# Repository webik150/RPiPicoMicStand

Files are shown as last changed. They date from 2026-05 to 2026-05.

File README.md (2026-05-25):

# Rapic Micsta
-# Raspberry Pi Pico Microphone Stand

This project aims to create a motorized microphone stand using old NEMA-17 stepper motors from Prusa MK3, controllable through a LAN web server hosted on a RPi Pico W using MicroPython.

The software part operates in two modes:

- **Pairing Mode**: When no Wi-Fi credentials are available at startup, or wi-fi connection is unsuccessful, the device creates a Wi-Fi Access Point (AP) and serves as a captive portal to allow users to configure the Wi-Fi settings. It is also possible to control the stand in this way in case you need to record in the field without any wifi for whatever reason.
- **Work Mode**: Once Wi-Fi credentials are saved, the device connects to the saved network and serves a control website on the local network.

### Updates
- **2025-04-21**: Update PCB to V2.1. It uses a much simpler and cheaper design. It's now just 2 layers instead of 4 and should be compatible with more types of TMC2209.
- **2024-12-15**: Made a V2 of the PCB, it's much smaller, uses SMD components and TMC2209 instead of A4988. I also added a connector for an OLED display.
- **2024-11-02**: PCB was tested out to be working so I added files for it along with pics. Feel free to have it made, I usually use JLCPCB for that. I also added an 8SEG display to the thing last minute, which means there's no connector for it on the PCB, however you can just solder 4 pins to the top of the Pico like in the pic below.

## Features
- Movement on X and Y axes (Forward/Back and Left/Right)
- Mic rotation on one axis
- Optional 8SEG display for debugging, info, stuff.
- Powered by 12V, idk how many A will be needed yet.
- I'll try to make as much of the actual structure 3D printable
- The software side is just a HTML page that sends commands through AJAX rn.

## Requirements

- **Hardware**:
  - PCB V2
    - 1x Raspberry Pi Pico W (Pico W 1 is recommended for now as Pico W 2 micropython is in pre-release)
    - 3x TMC2209. I'm using black+green V2, others *should* work, but sometimes the pin layout differs.
    - 1x 12V 3A power supply
    - 5V Buck converter (most I've seen support different input voltages 5-30V). Should support 3A.
    - (optionally) SSD1306 OLED display. 128x64 works out of the box, 128x32 needs additional tweaks.
  - Stand itself
    - No idea yet.

- **Software**:
  - MicroPython installed on the Pico W
  - MicroPython modules:
    - `network` for Wi-Fi functionality
    - `socket` for HTTP server implementation
    - `ujson` for saving/loading Wi-Fi credentials

## Installation & Setup
idk if this is correct, ChatGPT came up with these instructions and I haven't had time to check them yet lol.

1. **Flash MicroPython on Raspberry Pi Pico W**:
    - Download the MicroPython firmware for Pico W from [here](https://micropython.org/download/rp2-pico-w/).
    - Flash the firmware to your Pico W using the Thonny IDE or another method.

2. **Clone the Repository**

3. **Upload Files to Pico W**:
    - Use Thonny or another IDE to upload the required Python files to your Pico W. The key files include:
        - `main.py`: The main logic for the pairing mode, Wi-Fi connection, and work mode.
        - `img/`: Folder containing images for the UI.
        - `index.html`: The control webpage.
        - `modules/`: Folder containing Python modules for the HTTP server and Wi-Fi configuration.

4. **Modify the Configuration**:
    - If you want to set a custom SSID and password for the access point, edit the following lines in `main.py`:

5. **Running the Project**:
    - Plug in the Raspberry Pi Pico W, and the script will automatically run.
    - If the device is unable to connect to a Wi-Fi network, it will enter **Pairing Mode**, where you can connect to the access point `RPi_Pico_Setup` and configure the network settings.
    - Once the Wi-Fi credentials are applied, the Pico W will switch to **Work Mode** and serve the control webpage on the local network.

## Usage

### Pairing

1. Connect to the Wi-Fi access point `RPiMicStand` with the password `12345678`.
2. Your device (phone or computer) should automatically open a captive portal page.
3. Select a network from the dropdown and enter the Wi-Fi password.
4. Press "Apply" to save the credentials and switch to work mode.

### Work Mode

1. The Pico W connects to the saved Wi-Fi network and launches a web server on port `80`.
2. Access the control page by navigating to the Pico's IP address in a web browser (use `wlan.ifconfig()` to find the IP).
3. Use the sliders, buttons, and other controls on the page to interact with the Pico's GPIO pins or perform other tasks.

## PCB
KiCAD files are in the `PCB` folder. It could definitely be made much smaller, I might make a v2 sometime just for the fuck of it, or if necessary. 

Right now RaPiPiMiSt uses 14 GPIO pins (3 for each motor, 5 for the display).

### Possible improvements (V2 Wishlist):
  * Use SMD components instead of THT. It's just resistors and capacitors so nothing fancy.
  * Get rid of the DIP switches and control the pins through Pico, there's enough PINS still.
    * Should this even be configurable? I could theoretically hardwire it so that X/Y motors use 1/2 step and Z motor uses 1/16 step.
    * If configurable, each motor would use 6 pins (23 total, which still fits). Alternatively only Z axis could be configurable.
  * Add a connector for the display directly on the board
  * Maybe switch over to an OLED display, which is cheaper, much more versatile and uses one less pin.
    * Downside is I have to learn to make an UI for that, but it sounds fun.
  * The power pin is made for a classic dupont pin rn, might be better to put it on the edge somewhere and make it use an actual on-board connector. Less wires.
  * I limited myself to 2 layer PCB, but 4 layer one isn't actually that much more expensive and could make stuff much smaller.
  * The A4988 is loud and has no stall detection. I could switch to a TMC2209 which is bit more expensive but would allow for automatic calibration and less pins used.
  * Idk what the fail rate of these drivers is but they could be soldered to the board instead of using a socket.
  * I could actually use vias instead of trying to go around everything lol.
  * The pico could be soldered directly to the board without any headers

RaPiPiMiSt PCB v01
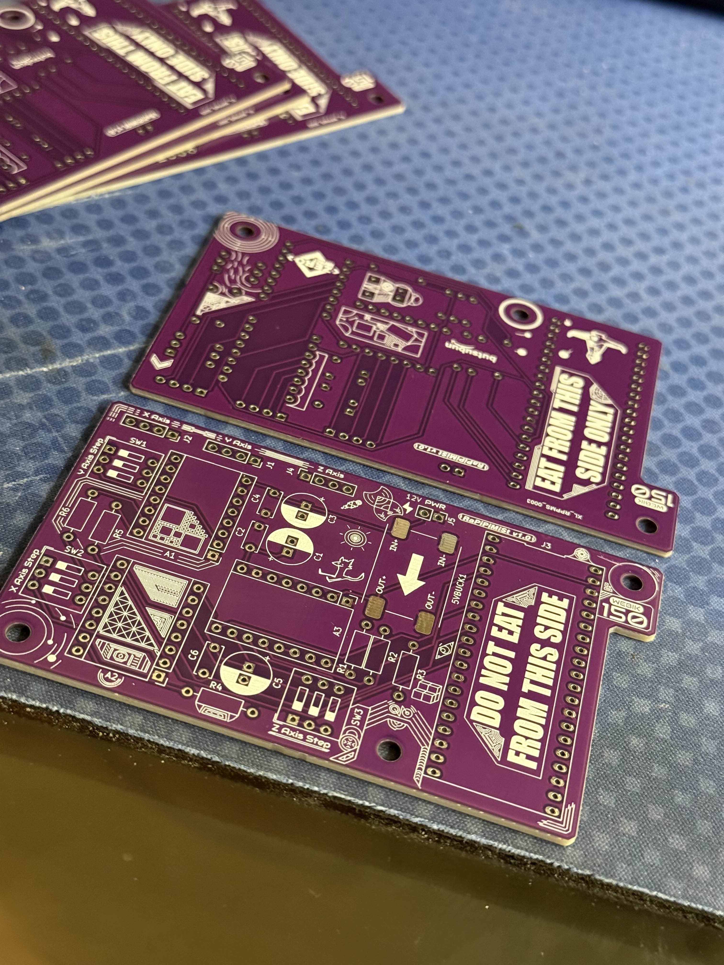
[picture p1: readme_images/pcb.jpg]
Plain PCB

Finished thing
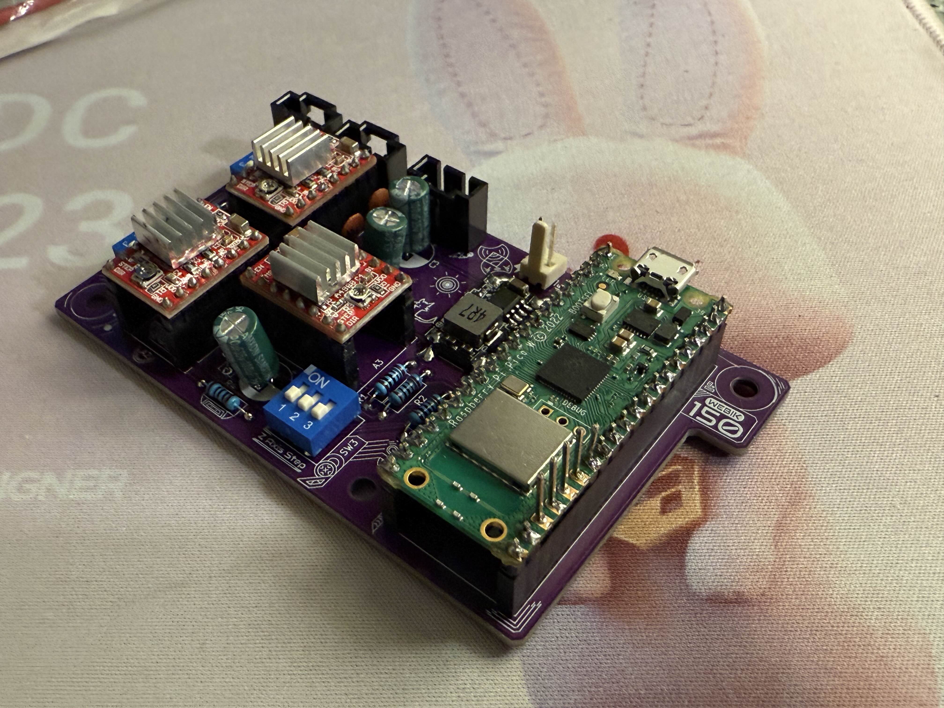
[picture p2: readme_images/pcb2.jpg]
Soldered PCB


## Pics

**Control website**:
TODO
Captive Portal

**Stand**:
TODO
Captive Portal

## License

This project is licensed under the MIT License. See the [LICENSE](LICENSE) file for details.

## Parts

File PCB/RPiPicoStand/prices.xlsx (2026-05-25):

Reference | Value | Datasheet | Footprint | Qty | DNP | Price per lot | Price Total | Price Total for single board
5VBUCK1 | ~ |  | Library:BUCK Converter 5-30V 5V 3A smd | 1 | 13.6 | 68 | 13.6 | 68
A1,A2,A3 | Pololu_Breakout_A4988 | https://www.pololu.com/product/2980/pictures | Module:Pololu_Breakout-16_15.2x20.3mm | 3 | 26.6 | 133 | 79.8 | 133
C1,C3,C5 | C_Polarized_Small | ~ | Capacitor_THT:CP_Radial_D7.5mm_P2.50mm | 3 | 1 | 130 | 3 | 130
C2,C4,C6 | C_Small | ~ | Capacitor_THT:C_Disc_D6.0mm_W2.5mm_P5.00mm | 3 | 1 | 140 | 3 | 140
J1,J2,J4 | Conn_01x04_Pin | ~ | Connector_PinSocket_2.54mm:PinSocket_1x04_P2.54mm_Vertical | 3 | 10 | 100 | 30 | 100
J3 | Conn_02x20_Counter_Clockwise | ~ | Connector:DIP-40_709_ELL socket W18Pins W21 | 1 | 5 | 25 | 5 | 25
J5 | Conn_01x02_Pin | ~ | Connector_PinHeader_2.54mm:PinHeader_1x02_P2.54mm_Vertical | 1 | 1 | 10 | 1 | 10
R1,R2,R3,R4,R5,R6 | R_Small | ~ | Resistor_THT:R_Axial_DIN0207_L6.3mm_D2.5mm_P10.16mm_Horizontal | 6 | 1 | 100 | 6 | 100
SW1,SW2,SW3 | SW_DIP_x03 | ~ | Button_Switch_THT:SW_DIP_SPSTx03_Slide_9.78x9.8mm_W7.62mm_P2.54mm | 3 | 32 | 32 | 96 | 32
Rpi Pico W |  |  |  | 1 | 150 | 150 | 150 | 150
PCB |  |  |  | 1 | 50 | 250 | 50 | 250
 |  |  |  |  |  |  | 437.4 | 1138

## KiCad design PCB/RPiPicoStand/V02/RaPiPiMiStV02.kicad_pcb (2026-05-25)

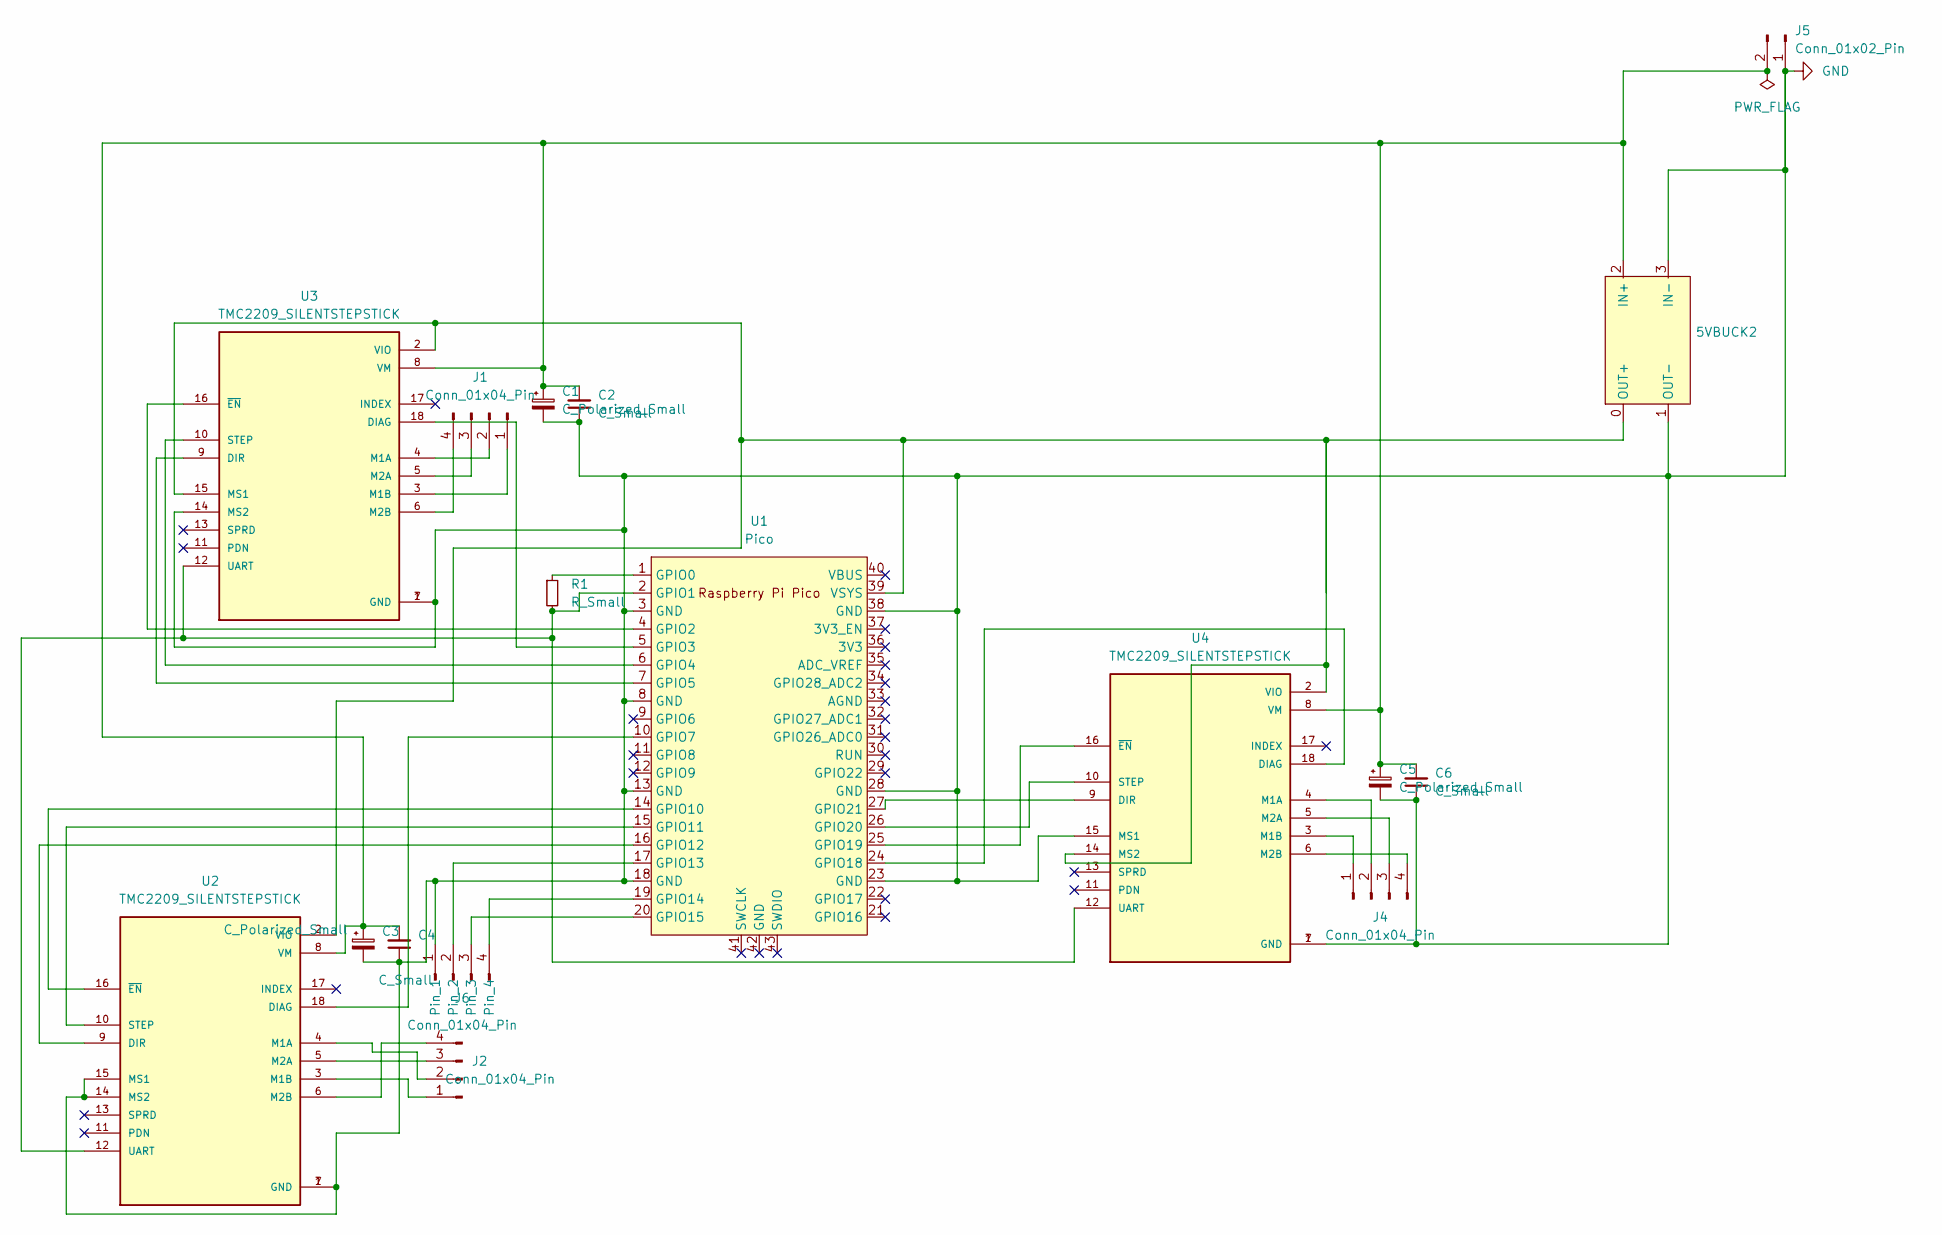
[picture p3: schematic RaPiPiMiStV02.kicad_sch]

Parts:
5VBUCK2: BUCK Converter 5-30V 5V 3A smd
C1, C3, C5: C_Polarized_Small; CP_Elec_6.3x7.7
C2, C4, C6: C_Small; C_0603_1608Metric
J1, J2, J4, J6: Conn_01x04_Pin; PinSocket_1x04_P2.54mm_Vertical
J5: Conn_01x02_Pin; PinHeader_1x02_P2.54mm_Vertical
R1: R_Small; R_0603_1608Metric_Pad0.98x0.95mm_HandSolder
U1: Pico; RPi_Pico_SMD_TH
U2, U3, U4: TMC2209_SILENTSTEPSTICK; MODULE_TMC2209_SILENTSTEPSTICK; PARTREV 1.20

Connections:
GND: 5VBUCK2.1 (OUT-), 5VBUCK2.3 (IN-), C1.2, C2.1, C3.2, C4.1, C5.2, C6.1, J5.1, J6.1, U1.3 (GND), U1.8 (GND), U1.13 (GND), U1.18 (GND), U1.23 (GND), U1.28 (GND), U1.38 (GND), U2.1 (GND), U2.7 (GND), U2.14 (MS2), U2.15 (MS1), U3.1 (GND), U3.7 (GND), U3.14 (MS2), U4.1 (GND), U4.7 (GND), U4.15 (MS1)
unnamed: 5VBUCK2.2 (IN+), C1.1, C2.2, C3.1, C4.2, C5.1, C6.2, J5.2, U2.8 (VM), U3.8 (VM), U4.8 (VM)
unnamed: 5VBUCK2.0 (OUT+), U1.39 (VSYS), U2.2 (VIO), U3.2 (VIO), U3.15 (MS1), U4.2 (VIO), U4.14 (MS2)
unnamed: J1.1, U3.3 (M1B)
unnamed: J1.2, U3.4 (M1A)
unnamed: J1.3, U3.5 (M2A)
unnamed: J1.4, U3.6 (M2B)
unnamed: J2.1, U2.3 (M1B)
unnamed: J2.2, U2.4 (M1A)
unnamed: J2.3, U2.5 (M2A)
unnamed: J2.4, U2.6 (M2B)
unnamed: J4.1, U4.3 (M1B)
unnamed: J4.2, U4.4 (M1A)
unnamed: J4.3, U4.5 (M2A)
unnamed: J4.4, U4.6 (M2B)
unnamed: J6.2, U1.17 (GPIO13)
unnamed: J6.3, U1.20 (GPIO15)
unnamed: J6.4, U1.19 (GPIO14)
unnamed: R1.1, U1.1 (GPIO0)
unnamed: R1.2, U1.2 (GPIO1), U2.12 (UART), U3.12 (UART), U4.12 (UART)
unnamed: U1.4 (GPIO2), U3.16 (~EN)
unnamed: U1.5 (GPIO3), U3.18 (DIAG)
unnamed: U1.6 (GPIO4), U3.10 (STEP)
unnamed: U1.7 (GPIO5), U3.9 (DIR)
unnamed: U1.10 (GPIO7), U2.18 (DIAG)
unnamed: U1.14 (GPIO10), U2.16 (~EN)
unnamed: U1.15 (GPIO11), U2.10 (STEP)
unnamed: U1.16 (GPIO12), U2.9 (DIR)
unnamed: U1.24 (GPIO18), U4.18 (DIAG)
unnamed: U1.25 (GPIO19), U4.16 (~EN)
unnamed: U1.26 (GPIO20), U4.10 (STEP)
unnamed: U1.27 (GPIO21), U4.9 (DIR)

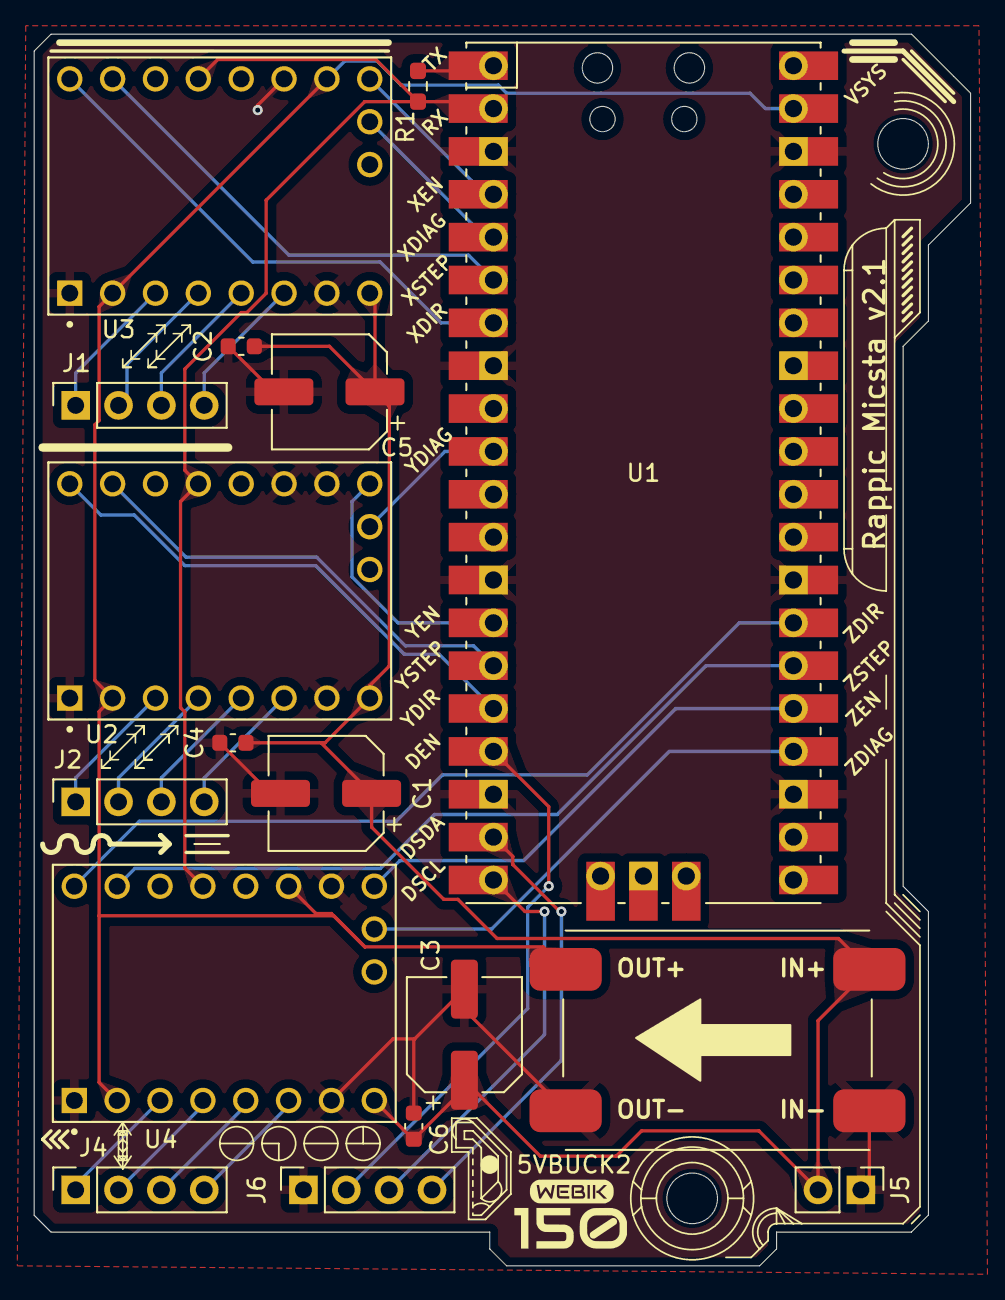
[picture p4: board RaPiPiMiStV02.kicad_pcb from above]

Board: 2 copper layers, 55.5 x 73.0 mm, 17 parts (0 on the bottom side), 32 nets.

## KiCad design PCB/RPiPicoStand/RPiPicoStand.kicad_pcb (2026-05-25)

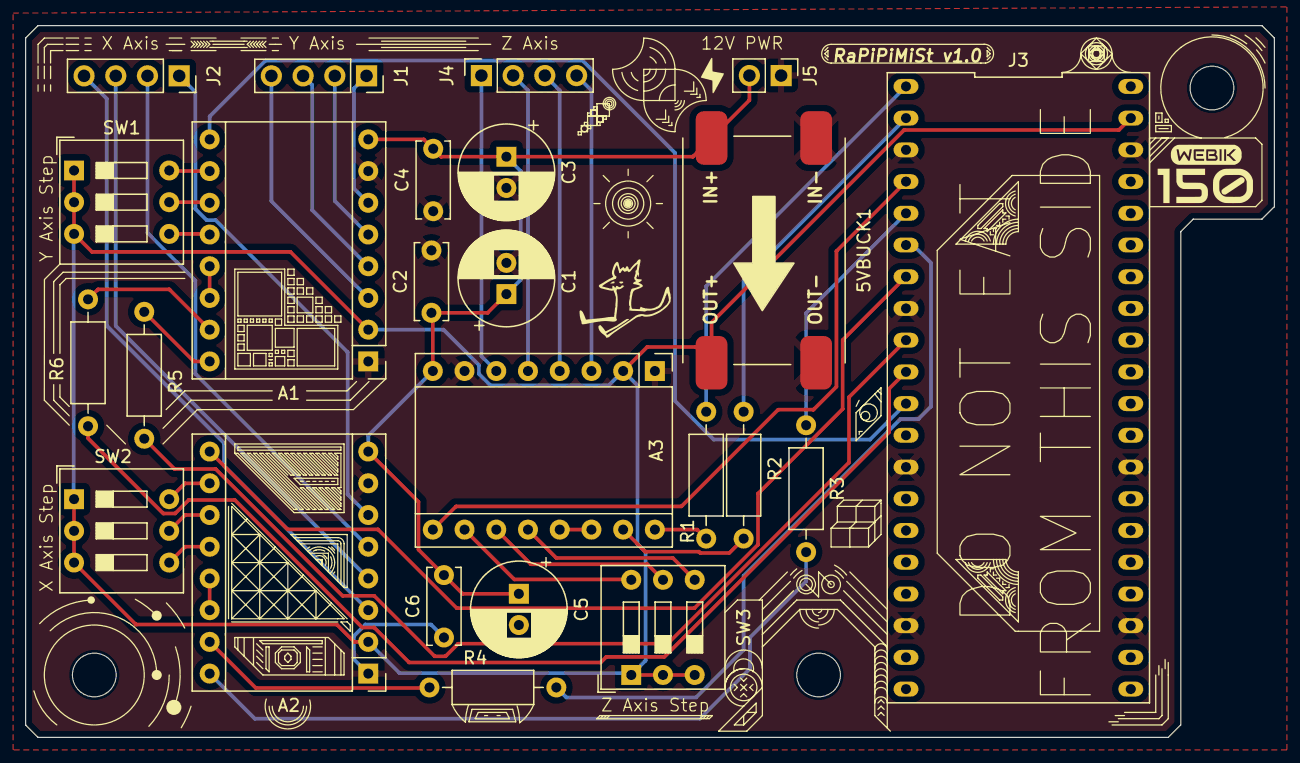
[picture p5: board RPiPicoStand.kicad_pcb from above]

Board: 2 copper layers, 100.0 x 57.0 mm, 25 parts (1 on the bottom side), 39 nets.

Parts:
5VBUCK1: BUCK Converter 5-30V 5V 3A smd
A1, A2, A3: Pololu_Breakout_A4988; Pololu_Breakout-16_15.2x20.3mm
C1, C3, C5: C_Polarized_Small; CP_Radial_D7.5mm_P2.50mm
C2, C4, C6: C_Small; C_Disc_D6.0mm_W2.5mm_P5.00mm
J1, J2, J4: Conn_01x04_Pin; PinSocket_1x04_P2.54mm_Vertical
J3: Conn_02x20_Counter_Clockwise; DIP-40_709_ELL socket W18Pins W21
J5: Conn_01x02_Pin; PinHeader_1x02_P2.54mm_Vertical
R1, R2, R3, R4, R5, R6: R_Small; R_Axial_DIN0207_L6.3mm_D2.5mm_P10.16mm_Horizontal
SW1, SW2, SW3: SW_DIP_x03; SW_DIP_SPSTx03_Slide_9.78x9.8mm_W7.62mm_P2.54mm
aa: LOGO

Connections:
GND: 5VBUCK1.1 (OUT-), 5VBUCK1.3 (IN-), A1.1 (GND), A1.7 (GND), A2.1 (GND), A2.7 (GND), A3.1 (GND), A3.7 (GND), C1.2, C2.1, C3.2, C4.1, C5.2, C6.1, J3.3, J3.8, J3.13, J3.18, J3.23, J3.28, J3.38, J5.1
unnamed: 5VBUCK1.2 (IN+), A1.8 (VMOT), A2.8 (VMOT), A3.8 (VMOT), C1.1, C2.2, C3.1, C4.2, C5.1, C6.2, J5.2
unnamed: 5VBUCK1.0 (OUT+), A1.2 (VDD), A2.2 (VDD), A3.2 (VDD), J3.39, SW1.1, SW1.2, SW1.3, SW2.1, SW2.2, SW2.3, SW3.1, SW3.2, SW3.3
unnamed: A1.4 (1A), J1.3
unnamed: A1.3 (1B), J1.4
unnamed: A1.5 (2A), J1.2
unnamed: A1.6 (2B), J1.1
unnamed: A1.16 (DIR), R5.2
unnamed: A1.10 (MS1), SW1.6
unnamed: A1.11 (MS2), SW1.5
unnamed: A1.12 (MS3), SW1.4
unnamed: A1.15 (STEP), R6.1
unnamed: A1.9 (~ENABLE), J3.11
unnamed: A2.4 (1A), J2.3
unnamed: A2.3 (1B), J2.4
unnamed: A2.5 (2A), J2.2
unnamed: A2.6 (2B), J2.1
unnamed: A2.16 (DIR), R3.1
unnamed: A2.10 (MS1), SW2.6
unnamed: A2.11 (MS2), SW2.5
unnamed: A2.12 (MS3), SW2.4
unnamed: A2.15 (STEP), R4.1
unnamed: A2.9 (~ENABLE), J3.7
unnamed: A3.4 (1A), J4.3
unnamed: A3.3 (1B), J4.4
unnamed: A3.5 (2A), J4.2
unnamed: A3.6 (2B), J4.1
unnamed: A3.16 (DIR), R1.1
unnamed: A3.10 (MS1), SW3.6
unnamed: A3.11 (MS2), SW3.5
unnamed: A3.12 (MS3), SW3.4
unnamed: A3.15 (STEP), R2.1
unnamed: A3.9 (~ENABLE), J3.4
unnamed: J3.1, R1.2
unnamed: J3.2, R2.2
unnamed: J3.5, R3.2
unnamed: J3.6, R4.2
unnamed: J3.9, R5.1
unnamed: J3.10, R6.2

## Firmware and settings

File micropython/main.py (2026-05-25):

import sys
import utime
import network
import uasyncio
from modules.log import Log
from modules.rpicostand import RPicoStand
# server
from phew import logging, server, access_point, dns, connect_to_wifi
from phew.template import render_template
from phew.server import redirect, Response
from machine import Pin

# while True:
#     sparkle_dissolve(rpicostand.display.oled, 1000, 50)
#     expanding_polygon(rpicostand.display.oled, center_x=64, center_y=16, duration_ms=500, sides=6, initial_rotation=30)
#     expanding_polygon(rpicostand.display.oled, center_x=64, center_y=16, duration_ms=500, sides=6, initial_rotation=0)
#     expanding_polygon(rpicostand.display.oled, center_x=64, center_y=16, duration_ms=500, sides=4, initial_rotation=0)
#     expanding_polygon(rpicostand.display.oled, center_x=64, center_y=16, duration_ms=500, sides=3, initial_rotation=0)
#     expanding_polygon(rpicostand.display.oled, center_x=64, center_y=16, duration_ms=500, sides=16, initial_rotation=0)
#     random_expanding_polygons(rpicostand.display.oled, duration_ms=100, num=5, state=1)
#     random_expanding_polygons(rpicostand.display.oled, duration_ms=100, num=5, state=0)
#     random_expanding_polygons(rpicostand.display.oled, duration_ms=100, num=5, state=-1)
from modules.displays import OLED_SSD1306

print("Starting up")
led = Pin("LED", Pin.OUT)
led(1)
Pin(21, Pin.OUT)(1)
utime.sleep_ms(500)
led(0)


@server.route("/", methods=['GET', 'POST'])
def index(request):
    """ Render the Index page and respond to form requests """
    if request.method == 'GET':
        # logging.debug("Get request")
        # give the webpage access to python variables
        return index_page()
    if request.method == 'POST':
        text = request.form.get("text", None)
        #logging.debug(f'posted message: {text}')
        return index_page()

@server.route("/restart", methods=['POST'])
def restart(request):
    #uasyncio.create_task(restart_after_while())
    rpicostand.display.oled.fill(0)
    rpicostand.display.display_centered_text("Restarting...", 8)
    utime.sleep_ms(500)
    sys.exit()
    return Response("Restarting...", status=200, headers={"Content-Type": "text/html"})

@server.route("/configure", methods=['POST'])
def configure(request):
    """ Render the Index page and respond to form requests """
    if request.method == 'POST':
        reboot_required = False
        config_changed = False
        ssid = request.form.get("ssid", None)
        password = request.form.get("password", None)
        new_hostname = request.form.get("hostname", None)
        new_x_speed = request.form.get("x_speed", None)
        new_y_speed = request.form.get("y_speed", None)
        new_z_speed = request.form.get("z_speed", None)

        if ssid and password:
            Log.log_data("Saving credentials!")
            rpicostand.save_wifi_credentials(ssid, password)
            reboot_required = True
            config_changed = True

        if new_hostname and new_hostname != network.hostname():
            Log.log_data(f"Changing hostname to {new_hostname}")
            network.hostname(new_hostname)
            reboot_required = True
            config_changed = True

        if new_x_speed:
            # parse to list of ints
            # remove any non-numeric characters except commas
            new_x_speed = ''.join([x for x in new_x_speed if x.isdigit() or x == ','])
            new_x_speed = [int(x) for x in new_x_speed.split(",")]
            if new_x_speed != rpicostand.motors['x'].speeds and len(new_x_speed) == 3:
                Log.log_data(f"Changing x speeds to {new_x_speed}")
                rpicostand.motors['x'].speeds = new_x_speed
                config_changed = True
            else:
                Log.log_data(f"Invalid x speeds: {new_x_speed}")

        if new_y_speed:
            # parse to list of ints
            # remove any non-numeric characters except commas
            new_y_speed = ''.join([x for x in new_y_speed if x.isdigit() or x == ','])
            new_y_speed = [int(x) for x in new_y_speed.split(",")]
            if new_y_speed != rpicostand.motors['y'].speeds and len(new_y_speed) == 3:
                Log.log_data(f"Changing y speeds to {new_y_speed}")
                rpicostand.motors['y'].speeds = new_y_speed
                config_changed = True
            else:
                Log.log_data(f"Invalid y speeds: {new_y_speed}")

        if new_z_speed:
            # parse to list of ints
            # remove any non-numeric characters except commas
            new_z_speed = ''.join([x for x in new_z_speed if x.isdigit() or x == ','])
            new_z_speed = [int(x) for x in new_z_speed.split(",")]
            if new_z_speed != rpicostand.motors['z'].speeds and len(new_z_speed) == 3:
                Log.log_data(f"Changing z speeds to {new_z_speed}")
                rpicostand.motors['z'].speeds = new_z_speed
                config_changed = True
            else:
                Log.log_data(f"Invalid z speeds: {new_z_speed}")

        if config_changed:
            rpicostand.save_configuration()

        if reboot_required:
            uasyncio.create_task(restart_after_while())
            return Response("Credentials saved! The machine will now restart.", status=200,
                            headers={"Content-Type": "text/html"})
        else:
            return Response("Changes saved", status=200, headers={"Content-Type": "text/html"})


@server.route("/wrong-host-redirect", methods=["GET"])
def wrong_host_redirect(request):
    # if the client requested a resource at the wrong host then present
    # a meta redirect so that the captive portal browser can be sent to the correct location
    body = f"<!DOCTYPE html><head><meta http-equiv=\"refresh\" content=\"0;URL=\'http://{DOMAIN}\'/ /></head>"
    logging.debug("body:", body)
    return body


@server.route("/hotspot-detect.html", methods=["GET"])
def hotspot(request):
    """ Redirect to the Index Page """
    #return render_template("index.html", disco = str(disco))
    return index_page()


@server.route("/move", methods=["POST"])
def move_motor(request):
    motor = request.data.get("axis", None)
    direction = request.data.get("direction", None)
    speed = request.data.get("speed", None)
    rpicostand.display.display_centered_text(f"Moving {motor}.", 8)
    rpicostand.display.display_centered_text(f"{direction}, {speed}", 16)

    if rpicostand.motors.get(motor) is None:
        Log.log_data(f"Invalid motor: {motor}")
        return Response("Invalid motor", status=400, headers={"Content-Type": "text/html"})
    if speed <= 0:
        rpicostand.motors[motor].stop()
        return Response(f"Motor {motor} stopped", status=200, headers={"Content-Type": "text/html"})
    if direction not in ['cw', 'ccw']:
        Log.log_data(f"Invalid direction: {direction}")
        return Response("Invalid direction", status=400, headers={"Content-Type": "text/html"})

    rpicostand.motors[motor].set_direction(direction)
    rpicostand.motors[motor].rotate(speed)

    return Response(f"Motor {motor} moved", status=200, headers={"Content-Type": "text/html"})


@server.route("/stop", methods=["POST"])
def stop_moving_motors(request):
    for motor in rpicostand.motors:
        rpicostand.motors[motor].stop()
    rpicostand.display.display_centered_text("Motors stopped.", 8)
    return Response(f"Motors stopped", status=200, headers={"Content-Type": "text/html"})


@server.route("/log", methods=["GET"])
def fetch_log(request):
    # if any motor is running, return a 503
    for motor in rpicostand.motors:
        if rpicostand.motors[motor].moving:
            return Response("Motors are moving", status=503, headers={"Content-Type": "text/html"})
    return Response(Log.read_log(), status=200, headers={"Content-Type": "text/html"})


#@server.catchall()
def catch_all(request):
    """ Catch and redirect requests """
    if request.headers.get("host") != DOMAIN:
        return redirect("http://" + DOMAIN)


async def restart_after_while():
    await uasyncio.sleep_ms(2000)
    del rpicostand
    raise SystemExit

def index_page():
    # turn speeds into comma separated strings
    return render_template("index.html",
                           hostname=network.hostname(),
                           networks_list=rpicostand.networks,
                           device_log=Log.read_log(),
                           current_mode="Work Mode" if rpicostand.wifi['ssid'] and rpicostand.wifi['password'] else "Pairing Mode",
                           x_speed=','.join([str(x) for x in rpicostand.motors['x'].speeds]),
                            y_speed=','.join([str(x) for x in rpicostand.motors['y'].speeds]),
                            z_speed=','.join([str(x) for x in rpicostand.motors['z'].speeds])
                           )


async def start_work_mode():
    Log.log_data("Starting work mode...")
    # should already be connected to wifi, so just start the server
    await rpicostand.initialize()
    #await rpicostand.initialize()
    server.run(host="0.0.0.0", port=80)  # Run the server
    Log.log_data("Work mode started.")



async def start_pairing_mode():
    Log.log_data("Starting Captive Portal...")
    # Set to Accesspoint mode
    ap = access_point("RPiPicoMicStand", "PicoStand123")  # NAME YOUR SSID
    ip = ap.ifconfig()[0]  # Grab the IP address and store it
    Log.log_data(f"starting DNS server on {ip}")
    dns.run_catchall(ip)  # Catch all requests and reroute them
    rpicostand.blink_led(100, 2000)
    server.run(host="0.0.0.0", port=80)  # Run the server
    # logging.info("Webserver Started")
    Log.log_data("Captive Portal started.")


def scan_networks():
    # Enumerate available networks
    wlan = network.WLAN(network.STA_IF)
    wlan.active(True)
    rpicostand.blink_led(1, 200)
    rpicostand.networks = wlan.scan()
    Log.log_data("Scanning for networks...")
    Log.log_data(rpicostand.networks)
    # join networks object to string
    rpicostand.blink_led(1, 200)
    wlan.active(False)
    return rpicostand.networks


async def try_connect_to_wifi(ssid, password):
    if not ssid or not password:
        Log.log_data("No Wi-Fi credentials found.")
        return False

    rpicostand.blink_led(50, 200)

    ip = connect_to_wifi(ssid, password, 10)
    if ip:
        Log.log_data(f"Connected to Wi-Fi. IP address: {ip}")
        rpicostand.display.fill(0)
        rpicostand.display.display_image('info', 0)
        await uasyncio.sleep_ms(1000)
        rpicostand.display.display_centered_text("connected.", 8)
        rpicostand.display.display_centered_text(f"{ip}", 0)

        # rpicostand.display_rolling_text("connected", .3)
        # rpicostand.display_rolling_text(f"{ip}", .5, 5)
        rpicostand.set_led(True)
        await uasyncio.sleep_ms(1000)
        return True
    else:
        Log.log_data("Failed to connect to Wi-Fi.")
        rpicostand.blink_led(20, 50)
        await  uasyncio.sleep_ms(1000)
        return False

utime.sleep(1)
rpicostand = RPicoStand()

async def main():
    # load configuration from file
    rpicostand.load_from_file("config.json")
    await rpicostand.show_boot_logo()
    # set machine hostname to DOMAIN
    network.hostname(rpicostand.hostname)

    Log.delete_log_on_startup()
    Log.log_data("Starting up...")
    # blinking thread
    rpicostand.blink_led(5, 100)

    scan_networks()

    if rpicostand.wifi['ssid'] and rpicostand.wifi['password']:
        Log.log_data("Wi-Fi credentials found.")
        rpicostand.blink_led(3, 500)
        success = await try_connect_to_wifi(rpicostand.wifi['ssid'], rpicostand.wifi['password'])
        if not success:
            rpicostand.blink_led(20, 50)
            Log.log_data("Failed to connect to Wi-Fi. Starting pairing mode...")
            rpicostand.display.oled.fill(0)
            rpicostand.display.oled.text("Failed to connect to Wi-Fi.", 0, 0, 1)
            rpicostand.display.oled.text("Starting pairing mode...", 0, 16, 1)
            rpicostand.display.oled.show()
            # rpicostand.display_rolling_text("internet error", .3, 1)
            # rpicostand.display_rolling_text("ap start", .3, 2)
            await start_pairing_mode()
        else:
            rpicostand.blink_led(3, 500)
            await start_work_mode()
    else:
        Log.log_data("No Wi-Fi credentials found. Starting pairing mode...")
        rpicostand.display.oled.fill(0)
        rpicostand.display.oled.text("No Wi-Fi credentials found.", 0, 0, 1)
        rpicostand.display.oled.text("AP Start.", 0, 16, 1)
        rpicostand.display.oled.show()
        # rpicostand.display_rolling_text("internet error", .3, 1)
        # rpicostand.display_rolling_text("ap start", .3, 2)
        rpicostand.blink_led(20, 50)
        await start_pairing_mode()

uasyncio.run(main())

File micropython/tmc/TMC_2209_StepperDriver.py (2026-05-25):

from modules.log import Log
from .TMC2209_uart import TMC_UART
from . import TMC2209_reg as reg
from machine import Pin as GPIO
import machine
import time
import math


class Direction():
    CCW = 0
    CW = 1


class Loglevel():
    none = 0
    error = 10
    info = 20
    debug = 30
    movement = 40
    all = 100


class MovementAbsRel():
    absolute = 0
    relative = 1


# -----------------------------------------------------------------------
# TMC_2209
#
# this class has two different functions:
# 1. change setting in the TMC-driver via UART
# 2. move the motor via STEP/DIR pins
# -----------------------------------------------------------------------
class TMC_2209:
    tmc_uart = None
    _pin_step = -1
    _pin_dir = -1
    _pin_en = -1
    p_pin_step = -1
    p_pin_dir = -1
    p_pin_en = -1

    _direction = True

    _stop = False

    _msres = -1
    _stepsPerRevolution = 0

    _loglevel = Loglevel.none

    _currentPos = 0  # current position of stepper in steps
    _targetPos = 0  # the target position in steps
    _speed = 0.0  # the current speed in steps per second
    _maxSpeed = 1.0  # the maximum speed in steps per second
    _maxSpeedHoming = 500  # the maximum speed in steps per second for homing
    _acceleration = 1.0  # the acceleration in steps per second per second
    _accelerationHoming = 10000  # the acceleration in steps per second per second for homing
    _sqrt_twoa = 1.0  # Precomputed sqrt(2*_acceleration)
    _stepInterval = 0  # the current interval between two steps
    _minPulseWidth = 1  # minimum allowed pulse with in microseconds
    _lastStepTime = 0  # The last step time in microseconds
    _n = 0  # step counter
    _c0 = 0  # Initial step size in microseconds
    _cn = 0  # Last step size in microseconds
    _cmin = 0  # Min step size in microseconds based on maxSpeed
    _sg_threshold = 100  # threshold for stallguard
    _movement_abs_rel = MovementAbsRel.absolute

    def mean(obj, x):
        a = 0
        for v in x:
            a = a + v
        return (a / len(x))

    # -----------------------------------------------------------------------
    # constructor
    # -----------------------------------------------------------------------
    def __init__(self, pin_step, pin_dir, pin_en, rx_pin, tx_pin, mtr_id=0, baudrate=115200, serialport=1):

        self.tmc_uart = TMC_UART(serialport, baudrate, rx_pin, tx_pin, mtr_id)
        self._pin_step = pin_step
        self._pin_dir = pin_dir
        self._pin_en = pin_en
        self.active = True
        #if (self._loglevel >= Loglevel.info):
        print("TMC2209: Init")
        self.p_pin_step = GPIO(self._pin_step, GPIO.OUT)
        self.p_pin_dir = GPIO(self._pin_dir, GPIO.OUT)
        self.p_pin_en = GPIO(self._pin_en, GPIO.OUT)
        self.p_pin_dir(self._direction)
        #if (self._loglevel >= Loglevel.info):
        print("TMC2209: GPIO Init finished")
        if not self.clearGSTAT():
            self.active = False
        else:
            self.readStepsPerRevolution()
        if not self.clearGSTAT():
            self.active = False
        self.tmc_uart.flushSerialBuffer()
        print("TMC2209: Init finished")

    # -----------------------------------------------------------------------
    # destructor
    # -----------------------------------------------------------------------
    def __del__(self):
        #if (self._loglevel >= Loglevel.info):
        print("TMC2209: Deinit")
        self.setMotorEnabled(False)
        GPIO.cleanup()

    # -----------------------------------------------------------------------
    # set the loglevel. See the Enum Loglevel
    # -----------------------------------------------------------------------
    def setLoglevel(self, loglevel):
        self._loglevel = loglevel

    # -----------------------------------------------------------------------
    # set whether the movment should be relative or absolute by default.
    # See the Enum MovementAbsoluteRelative
    # -----------------------------------------------------------------------
    def setMovementAbsRel(self, movement_abs_rel):
        self._movement_abs_rel = movement_abs_rel

    # -----------------------------------------------------------------------
    # read the register Adress "DRVSTATUS" and prints all current setting
    # -----------------------------------------------------------------------
    def readDRVSTATUS(self):
        print("TMC2209: ---")
        print("TMC2209: DRIVER STATUS:")
        drvstatus = self.tmc_uart.read_int(reg.DRVSTATUS)
        if (self._loglevel >= Loglevel.info):
            print("TMC2209:", bin(drvstatus))
        if (drvstatus & reg.stst):
            print("TMC2209: Info: motor is standing still")
        else:
            print("TMC2209: Info: motor is running")

        if (drvstatus & reg.stealth):
            print("TMC2209: Info: motor is running on StealthChop")
        else:
            print("TMC2209: Info: motor is running on SpreadCycle")

        cs_actual = drvstatus & reg.cs_actual
        cs_actual = cs_actual >> 16
        print("TMC2209: CS actual: " + str(cs_actual))

        if (drvstatus & reg.olb):
            print("TMC2209: Warning: Open load detected on phase B")

        if (drvstatus & reg.ola):
            print("TMC2209: Warning: Open load detected on phase A")

        if (drvstatus & reg.s2vsb):
            print("TMC2209: Error: Short on low-side MOSFET detected on phase B. The driver becomes disabled")

        if (drvstatus & reg.s2vsa):
            print("TMC2209: Error: Short on low-side MOSFET detected on phase A. The driver becomes disabled")

        if (drvstatus & reg.s2gb):
            print("TMC2209: Error: Short to GND detected on phase B. The driver becomes disabled. ")

        if (drvstatus & reg.s2ga):
            print("TMC2209: Error: Short to GND detected on phase A. The driver becomes disabled. ")

        if (drvstatus & reg.ot):
            print("TMC2209: Error: Driver Overheating!")

        if (drvstatus & reg.otpw):
            print("TMC2209: Warning: Driver Overheating Prewarning!")

        print("---")
        return drvstatus

    # -----------------------------------------------------------------------
    # read the register Adress "GCONF" and prints all current setting
    # -----------------------------------------------------------------------
    def readGCONF(self):
        print("TMC2209: ---")
        print("TMC2209: GENERAL CONFIG")
        gconf = self.tmc_uart.read_int(reg.GCONF)
        if (self._loglevel >= Loglevel.info):
            print("TMC2209:", bin(gconf))
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

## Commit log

2024-09-30 add test code for turning the motors
2024-09-30 add controls for individual motors
2024-10-01 create Motor class create RPicoStand class create JSON class with static methods for serializing and deserializing config change /configure endpoint to allow for setting motor speeds change how confi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
    [main.py]
2024-10-31 add pico 8-seg display support show status messages and device IP on wifi connection add static and rolling text support
2024-11-02 move display code to the main python file to decrease number of files needed to be flashed change motor pins to actually reflect the pins used by the PCB disable all motors on start
2024-11-02 update readme add some images
    [RPiPicoStand.kicad_pcb, RPiPicoStand.kicad_sch]
2024-11-05 add the whole KiCAD project
    [RPiPicoStand.kicad_pcb, RPiPicoStand.kicad_sch, RPiPicoStandAuto.kicad_pcb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]
2024-11-20 add V2 kicad project
    [RaPiPiMiStV02.kicad_pcb, RaPiPiMiStV02.kicad_sch, RaPiPiMiStV02Vertical.kicad_pcb]
2024-11-23 add icons and board bmp
2024-11-24 silkboard updates
    [RaPiPiMiStV02.kicad_pcb]
2024-11-24 add teardrops, fix planes
    [RaPiPiMiStV02.kicad_pcb]
2024-11-24 fix name of the pcb
    [RaPiPiMiStV02.kicad_pcb]
2024-11-26 factory outputs
    [RaPiPiMiStV02.kicad_pcb]
2025-03-31 Remove legacy frontend and backend code for RPi Pico Mic Stand
    Deleted unused `index.html` and `main.py` to clean up the repository. This removes obsolete web interface scripts, hardware control logic, and display effects to prepare for a streamlined implementat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
    [RaPiPiMiStV02.kicad_sch]
2025-03-31 fix uart connections on the PCB
    [RaPiPiMiStV02.kicad_pcb, RaPiPiMiStV02.kicad_sch]
2025-04-21 Update PCB design to V2.1 and adjust related files
    Updated the PCB to version 2.1, introducing a simpler and cheaper 2-layer design compatible with more TMC2209 types. Adjusted KiCad project settings, output directories, and port configurations to al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
    [RaPiPiMiStV02.kicad_pcb]
2025-04-21 Update README hardware section with clarification details
    Added recommendations for Raspberry Pi Pico W versions and noted potential pin layout differences for TMC2209 variants. Adjusted power supply voltage for accuracy and provided further clarification f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
2025-04-21 Optimize motor initialization and error handling
    Refactored motor initialization to include better GSTAT error checks and conditional setup functions, improving robustness. Removed redundant initialization code and centralized logic in `RPicoStand`. Streamlined logging and corrected pin configurations for consistency.
    [TMC2209_uart.py, TMC_2209_StepperDriver.py, main.py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]
2025-05-08 Refactor and enhance motor control and display initialization.
    Improved motor handling with new stallguard threshold testing, updated microstepping configurations, and enhanced homing routines. Display initialization now includes detection handling and improved timing. Removed redundant code and ensured more robust startup processes across modules.
    [TMC_2209_StepperDriver.py, displays.py, main.py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]
